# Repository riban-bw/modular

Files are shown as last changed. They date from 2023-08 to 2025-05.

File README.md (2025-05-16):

# riban modular

## Overview

Riban modular is an open source and (where practical) open hardware virtual modular synthesiser with physical control panels that fit the Eurorack physical format. See the [wiki](https://github.com/riban-bw/modular/wiki) for documentation.

There are hardware panels that represent each virtual module. The panels are plugged together via a daisy-chain ribbon cable which provides power and a CAN bus for inter-communication. Modules have rotary controls, switches, LEDs, etc. that mimic and control the virtual modules. A Raspberry Pi 5 forms the core, providing the audio processing and interfacing with the hardware panels. Panels are detected automatically when connected, creating a corresponding virtual module within the virtual modular system.

The system consists of a _Brain_ and panels. The Brain consists of a Raspberry Pi 5, STM32F103 microcontroller, CAN connector, audio interface and associated connectors, buttons, pots, etc. Panels consist of STM32F103 microcontroller, CAN connector and buttons, pots, etc.

Each panel is based on a STM32F103C8 microcontroller with a common firmware that supports various quantities and types of controls and indicators. Each panel has a type number that identifies what type of virtual module it represents.

Connect each module to a ribbon cable connector then power up the system. The core will communicate via CAN to detect which panels are installed, assign each panel an id then add a correspoding virtual module to its model.

## Usage

Hardware panels are required to interface with the firmware. See the [wiki](https://github.com/riban-bw/modular/wiki) for documentation.

## Building

There are two core elements to _riban modular_: Hardware panels (including the firmware that runs on them) and the core. Panel firmware is written in C++ for the STMicroelectronics STM32 range of ARM based microcontrollers. The core is written in C++ for the Raspberry Pi ARM based SBC. VSCode IDE is used by the developer with plugins including platformio, which provides the build platform for the STM32 firmware. VSCode is run on a development PC, connected via ssh to the target (Raspberry Pi) platform.

### Core

The core code runs on a Raspberry Pi (4 or later), running [DietPi](https://dietpi.com/) operating system. CMake is used as the build tool. We use some modules from Bogaudio so have a dependancy on their source code with a small patch to exclude the GUI code. To compile the code:

- Install dependencies, e.g. `sudo apt install build-essentials libjack-jackd2-dev git cmake nlohmann-json3-dev`
- Clone this repository, e.g. `git clone --recursive https://github.com/riban-bw/modular.git`
- Change to the directory, e.g. `cd modular/firmware/rmcore`
- Create a build directory, e.g. `mkdir build`
- Change to the build directory, e.g. `cd build`
- Create build files, e.g. `cmake ..`
- Build executable, e.g. `make`

An executable file called _rmcore_ is creaed in the build directory. This may be run with optional command line options, e.g. `rmcore -h` to show help / usage.

### Panels

Each panel has a platformio configuration. These build instructions are for platformio within vscode IDE. (You could just use platformio directly.) I have written up a [guide](https://github.com/riban-bw/blog/wiki/STM32--development-on-PlatformIO-in-VSCode-on-64-bi-ARM) to using platformio within vscode over ssh to a Raspberry Pi to develop STM32 code. Follow that guide to get a working build environment. There are sepearate platformio projects for each panel, defined by a _platformio.ini_ file in the panel's firmware directory.

- Within vscode, click on the platformio icon in the left toolbar.
- Click on "Open Folder" and open the panel directory.
- If this is the first time, platformio will download and install the STM32 toolkit which may take several minutes.
- Click on the tick icon in the bottom toolbar to build the project. First time build may take longer as it builds all the dependant libraries.

To switch panels, use vscode file menu, open folder... Each time a new panel project is opened for the first time, platformio takes some time to configure. (Even on subsequent switches, platformio can take some time to open a project.)

Be aware that rmcore is within the firmware directory but is not a panel firmware and should be built as described in the [above section](#core).

## CAN Protocol

Communication between the Brain and panels uses CAN two wire serial bus. CAN uses differential balanced cabling to provide robust, high speed communication over long distance. Detection of panels uses CAN extended frame format (to allow fewer frames during detection) whilst normal operation uses standad frame format (to allow shorter frames for realtime data). Each panel starts by advertising its 96-bit hardware UID (STM32 serial number). The Brain module detects new panels and negotiates a _panel id_ (1..63) for each. CAN uses a lowest-id-wins mechanism for bus arbitration which allows the Brain to negotiate each panel partaking in the detection process. The panel with the lowest UUID is assigned the next available panel id which then leaves the detection process and joins the pool of configured panels. The Brain iterates over all panels currently advertising their participation in the detection process.

Subsequent communication between the Brain and each panel is via CAN messages initiated by panels for sensor changes (switches, knobs, etc.) or the Brain for indications (LEDs, etc.). The message type is encoded in the CAN ID. Each panel uses CAN filters to only listen for messages from the Brain. Similarly the Brain listens for messages from panels. All CAN traffic occurs between STM32F103 based devices.

#### CAN Message Protocol

CAN message id is 11-bit (std) or 29-bit (ext) word.

Standard CAN format (11-bit id) is used for runtime realtime messages.

Extended CAN format (29-bit id) is used for configuration and firmware update.

#### CAN runtime realtime messages

Brain to panel (B→P) CAN ID: bit [0] = 0, bits [1:7] = panel id (1..63), bits [8:11] = opcode.

Panel to Brain (B←P) CAN ID: bits [0:7] = 0, bits [8:11] = opcode.

Brain to rmcore splits messages into whole bytes, i.e. CAN ID[1], opcode[1], data[8].

rmcore can send messages to the Brain by setting first byte to 0xFF or to a panel by setting first byte to panel (CAN) id.

CAN payload may have varying length (0..8 bytes) depending on message type.

Brain always listens for panel messages and may request values with appropriate commands. This is asynchronous.

Host (RPi) communicates with Brain via serial port, mostly using same CAN protocol, i.e. the Brain passes through the CAN messages. An exception is for panel detection which the Brain handles locally and passes a single message to the host after detecting each panel.

|B↔P| ID | OpCode | Payload | Purpose|
|---|---|---|---|---|
|B→P| LED | 0x01 | Index [0:7] Mode [0:7] RGB1 [0:23] RGB2 [0:23] | Set LED type and mode. RGB colours are both optional |
|B←P| ADC | 0x02 | PanelId [0:7] Index [0:7] Value [0:15] | ADC value|
|B←P| SW | 0x03 | PanelId [0:7] Index[0:7] EventType [0:7] | See below for event types |
|B←P| ENC | 0x04 | PanelId [0:7] Index [0:7] Value [0:7] | Encoder value +/- |
|B←P| PNL_DUMP | 0xF1 | PanelId [0:7] | Request panel to send its parameter values |
|B←P| ALIVE | 0x0E | | Sent periodically if no other data sent to support watchdog |
|B→P| RESET | 0x0F | | Request panel to reset to detection mode |
|B←H| NUM_PNL  | 0x01 | | Request quantity of detected panels
|B←H| PNL_INFO | 0x01 | | Request type of all panels
|B→H| PNL_INFO | 0x01 | PanelId [0:5] Type [0:31] UUID [0:95] Ver [0:31] | Panel type (sent when new panel detected or PNL_INFO requested)
|B→H| PNL_REMOVED | 0x02 | PanelId [0:5] UUID [0:95] |
|B←H| PNL_RUN  | 0x03 | | Request all panels go to run mode

##### LED Modes
|Value|Mode|
|---|---|
|0x00|Off|
|0x01|Colour 1 on|
|0x02|Colour 2 on|
|0x03|Flash colour 1 / colour 2|
|0x04|Fast flash colour 1 / colour 2|
|0x05|Pulse colour 1 / colour 2|
|0x06|Fast pulse colour 1 / colour 2|

##### Switch States
|Value|State|
|---|---|
|0x00|Release|Sent when a button is released less than 0.5s after it was pressed (short press) or after a long press has triggered|
|0x01|Press|Always sent when a button is pressed|
|0x02|Bold|Sent when a button is released more than 0.5s after it was pressed but a long press has not triggered|
|0x03|Long|Sent when a button is held for longer than 1.5s|

#### Panel Detection

Panels advertise themselves with a CAN message which the Brain detects and starts a negotation. Detection messages use extended CAN ID which is 29-bits long (compared with standard frames used for realtime messages which are 11-bits). Each panel advertises itself by encoding its 96-bit UUID in the CAN ID of 4 consecutive messages. Each message is acknowledged by the Brain, indicating which panel UUID are accepted. Only panels that match that segment of the UUID continue with the negotiation. Eventually only one panel remains and is assigned a panel ID. Finally the panel indicates it has accepted the panel, sending its type and version. This allows the Brain to build a table of panel UUID, panel ID and panel type so that the core can create the appropriate virtual modules. It also allows the Brain to know whether a panel is running old firmware, allowing firmware update. The table is used to ensure that existing panels that restart, e.g. after a firmware update get the same panel ID.

|B⬌P| ID | ID | Payload | Purpose |
|----|---|---|---|---|
|B←P| DETECT_1  | 0x1F<UUID[0:23]>  | | Notify Brain that panel is added to bus but not initialised |
|B→P| DETECT_1  | 0x1F000000 | UUID[0:23] | Brain acknowledges lowest UUID panels |
|B←P| DETECT_2  | 0x1E<UUID[24:47]> | | Panel requests detect stage 2 |
|B→P| DETECT_2  | 0x1E000000 | UUID[24:47] | Brain acknowledges lowest UUID panels |
|B←P| DETECT_3  | 0x1D<UUID[48:71]> | | Panel requests detect stage 3 |
|B→P| DETECT_3  | 0x1D000000 | UUID[48:71] | Brain acknowledges lowest UUID panels |
|B←P| DETECT_4  | 0x1C<UUID[71:95]> | | Panel requests detect stage 4 |
|B→P| DETECT_4  | 0x1C000000 | UUID[72:95] PanelID[0:7] | Brain acknowledges UUID of only remaining panel |
|B←P| ACK_ID | 0x1B0000<PanelId> | Type [0:31] Version [0:31] | Panel acknowledges ID and informs Brain of its version & type |

#### Broadcast messages and firmware update

The CAN ID 0x000 is used to broadcast messages to all panels. This is the highest priority CAN ID (lowest value wins all bus conflict negotiation) and is used for low latency messaging (e.g. synchronisation) and firmware update. The first byte of a broadcast payload data is the opcode for a command. All broadcast messages use standard (11-bit) CAN format.

Broadcast messages
|Dir | ID | ID | Payload | Purpose
|----|---|---|---|---
|B→P| BROADCAST | 0x00000000 | OPCODE[0:7] | Broadcast from Brain payload contains opcode (see below) |
|B→P| BROADCAST | 0x00000000 | 0x01 UUID[0:23] | Start detection - all panels should join detection without software reset |
|B→P| BROADCAST | 0x00000000 | 0x02 PanelType [0:23] Ver [0:31]  | Start firmware update |
|B→P| BROADCAST | 0x00000000 | 0x03 Checksum [0:31] | End firmware update |
|B→P| FIRMWARE  | 0x01000000 | Firmware Block [0:63] | Firmware update data block |
|B→P| BROADCAST | 0x00000000 | 0xFF | Full reset - all panels should perform software reset |

Firmware is started with the broadcast message (CAN ID=0x000) with opcode 0x02. The panel type and firmware version are sent in this message. Any panel of this type with an older firmware will join the firmware update. Subsequent firmware update messages use the CAN ID 0x400 (msb set) with 8 bytes of firmware data. Panels configure a CAN filter to listen to this address during firmware update only. Upon completion of firmware update the Brain sends broadcast message with opcode 0x03 and a 32-bit checksum of the firmware data. The Brain ends its firmware update. Panels validate the checksum then apply the new firmware, restart and advertise as new panels.

#### Watchdog

Each panel periodically sends an ALIVE message if no other message has been sent in the previous 1.5s. If the Brain has not received any message from a panel for longer than 2s it assumes the panel has been removed  from the bus and removes its entry from the panel table. This triggers removal of the corresponding virtual module.

## Configuration

Configuration is stored in config.json which is loaded before command line parameters are parsed, so command line parameters take precedent.

Global settings are defined in the "global" object.

```
{
    "global": { # Global settings
        "polyphony": 1 # Quantity of concurrent voices (1..16)
    }
}
```

Each panel is defined in "panel" object.

```
{
    "panels" : { # Object of panel types
        "1": { # Object of panel configuration indexed by panel type id
            "module": "vco", # Name of the module type this panel controls
            "buttons": [ # List of buttons, indexed by physical button number
                [0, # Button function (input, poly input, output, poly output, param)
                0], # Index of the parameter or input/output
                # .. more button configs
            ],
            "leds": [ # List of LEDs, indexed by physical LED number
                [0, # LED function  (input, poly input, output, poly output, param)
                0], # Index of parameter or input/output
                # ... more LEDs
            ],
            "adcs": [ # List of parameters, indexed by physical ADC number
                0, # Parameter index
                # ... more ADCs
            ]
            "encs": { # List of parameters, indexed by physical PEC11 encoder number
                0, # Parameter index
                # ... more encoders
            }
        }, # ... More panel types
    }
}
```

panel_types.h defines mapping of panel types to module types and defines the STM32F103 pins used for sensors (controls) on each panel. 

## License

_riban modular_ is free and open source software, avaialble for distibution, use and modification by all. It has three open source licences, each applied to different parts of the code. Each source code file (including headers) contain a copyright notice describing which license applies to that part of the code. If a file is missing this banner, LGPL v3 is applied.

### LGPL V3
LGPL v3 is used for the core software and some plugins. This protects the core application whilst allowing non-open source plugins to be hosted by exercising dynamic linking with runtime loading (plugin exception). The text of the LGPL v3 license is distributed with the source code within the file called, lgpl-3.0.txt and may also be obtained from https://www.gnu.org/licenses/lgpl-3.0.en.html.

### GPL V3
To support plugins derived from GPL licensed code, some plugins have been licenced using GPL v3. These plugins continue to be fully copy-left protected whilst also able to be loaded into the core application using dynamic linking with runtime loading (plugin exception). The text of the GPL v3 license is distributed with the source code within the file called, gpl-3.0.txt and may also be obtained from https://www.gnu.org/licenses/gpl-3.0.en.html.

### MIT
To encourage third party plugin developement, there is a plugin template released under MIT license. This permits the use of the template as the basis of new plugins with the option for the author to release the derived work under any other license. We encourage use of LGPL for plugins where an open source license is required or preferred.

### Guidance and advice for plugin creators

If you are creating plugins to run within _riban modular_, you may use the `template.h` and `template.cpp` files as the boiler plate code. These files are published under the MIT license, specifically to allow and encourage developers to create new plugins without restricitve licensing constraints. You may create a new plugin and use the _riban modular_ cmake based build system to create the shared library. You may release this under a license that best suits your use case. You must attribute riban ltd as the author of the original template code, as described in the template source code.

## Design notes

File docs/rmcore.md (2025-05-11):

# Anatomy of rmcore source code

## Introduction
_riban modular_ has a module called the _Brain_. This does all the DSP, much of the physical interfacing and handles the logic for modules and panel management. It consists of a SBC (Raspberry Pi) running DietPi (Debian based) OS, a STM32 based microcontroller and I2S based soundcard. The STM32 performs CAN bus management and communicates with the SBC via a serial port. The program running on the SBC is called rmcore. This manages the state model and is the subject of this document.

## Purpose
This document describes the structure and data flows of rmcore. It acts as an engineering guide for software and hardware developers.

## Source Code
The source code for rmcore consists of the following source files, stored in `firmware/rmcore/src` directory:

- rmcore.cpp Implementation of core functionality and logic.
- moduleManager.cpp Implementation of the ModuleManager class that manages individual modules.
- usart.cpp Implementation of serial port interface, including CAN messaging.
- util.cpp Implementation of command line output helper functions.

Corresponding header files that declare classes are stored in `firmware/rmcore/include` directory.

## Initialisation
_rmcore_ is a command line application writeen in C++. It has a `int main(int argc, char** argv)` initialisation function. The return code is non-zero on an error. Command line parameters are parsed based on standard short (-c) and long (--command) syntax.

At initialisation, a handler is defined for signals. This allows capture of signals like SIGINT, allowing clean exit from the main program loop.

The command line is parsed for options.

A configuration file in json format is loaded and parsed by `loadConfig()` function.

`g_poly` is checked to allow it to be set by config or command line.

The command line interface (CLI) is initialised, including loading previous sessions' history.

A jack client is created which is used to control routing and monitor for changes and errors, e.g. xruns.

Polyphony is set, based on configuration and command line parameters.

A state model is loaded from a snapshot file. This may be defined by a command line parameter or the previous state is restored.

A reset message is sent to the _Brain_ microcontroller which should trigger panels to enter detection mode.

## Main program loop

Current time is updated and per-second events triggered.

- Recently detected panels are set to run mode.
- Panels are checked and removed if no messages received in past 5s.
- If state has changed within previous minute, it is stored to a snapshot.

CLI messages are processed.

Hardware panels are processed, checking for change of parameters, buttons, etc. and reacting to panels being added.

LED state off each module is checked and hardware panels updated if change of state.

## Configuration

The `loadConfig()` and `saveConfig()` functions use a json formated configuration file. This configuration is held in the same format at runtime and accessed via nlohmann::json library. The configuration is loaded at start-up and saved at exit.

## Command line parsing

_rmcore_ uses standard *nix style command line arguments in the short (-c) and long (--command) format. The `bool parseCmdline(int argc, char** argv)` function takes the command line arguments and configures global variables using the getopt library. This is a fairly standard and simple, itarative loop that looks for each argument and parses via a `switch` statement.

## Helper print functions

There are three helper functions that act like `fprintf`, adding an appropriate prefix and directing to the apporopriate outpute (stdout or stderr). Output only occurs at the corresponding verbose level defined by command line argument -v, --verbose.

`void debug(const char *format, ...)` prints to stderr at debug verbose level with no prefix.
`void info(const char *format, ...)` prints to stdout at info and debug verbose levels with no prefix.
`void error(const char *format, ...)` prints to stderr at all* verbose levels with "ERROR: " prefix.

* There is no output at silent verbose level.

## Command line interface (CLI)

The `readline` library is used to provide a CLI with history. The CLI history is saved on exit and restored on startup. During each main program loop, stdin is checked for a character which is added to the CLI input buffer. When a newline is detected, `void handleCli(char* line)` is called which parses the line and triggers actions. Most actions are single character commands, prefixed with '.', followed immediately by the first parameter with subsequent parameters seperated by commas with no white space (other than required within a parameter), e.g. ".svco,0,1.2" to set the first parameter of the "vco" module to a value of 1.2.

The stdin check has a 10us timeout which, when no key has been pressed, provides sufficient delay in main loop to avoid high CPU usage.

## Jack client

During initalisation, a jack client is created and callbacks configured port connect / disconnect and xrun. Port connection is only used for debug. Xrun count is maintained and available for debug and/or display.

The jack client is used to manipulate the jack graph. `bool connect(std::string source, std::string destination)` connects two nodes. `bool disconnect(std::string source, std::string destination)` disconnects two nodes. If a port is defined as polyphonic then all polyphonic connections are controlled. Polyphonic ports are suffixed with "[x]" where 'x' is the polyphony channel.

The jack client is used to get the jack graph state during saving of snapshots and is deactivated during exit.

## Module manager

During initialisation, an instance of a singleton class `ModuleManager` is created. This manages module plugins and is described in more detail in other documentation.

## State snapshot management

The runtime model state is stored to and recalled from _snapshot_ files with filename extenstion ".rms" (riban modular snapshot (or state)). This is in the _json_ format. Snapshots are stored in the "snapshot" subdirectory of the "config" directory. `void loadState(const std::string& filename)` opens the file and iterates each line, looking for "[section]" and "param=value" entries, populating the runtime state. Similarly, `void saveState(const std::string& filename)` iterates the runtime state, storing these entries in the file.

## Core / Brain interface

There is a serial port connection between the SBC and _Brain_ STM32 module which is used for communication between _rmcore_ and the module hardware. The `USART` class handles this communication and is documented elsewhere. _rmcore_ uses an instance of `USART` to send commands to the _Brain_ with _void txCmd(uint8_t cmd)` and directly to panels via the _Brain's_ CAN bus pass-through, `void txCAN(uint8_t pnlId, uint8_t opcode, uint8_t* data, uint8_t len)`.

Within the main progam loop, `bool processPanels()` is called approximately every millisecond. This reads messages from the USART into a buffer then parses complete messages. (See USART documentation for details of on-the-wire data encoding using COBS.) Changes of state in the hardware are detected. Model state and module plugins are updated.

`void processLeds()` is also called approximately every millisecond. This checks if any modules have changed the state of their LEDs and sends corresponding CAN messages through the _brain_ to panels which update their physical displays. There are LED states which define the behaviour or each LED. The hardware panels perform the animation, like pulsing which reduces traffic on the CAN bus and processing in _rmcore_.

## Realtime processing

All realtime processing is done within each module's _process()_ function which is called by its jack client. See module documentation for detail. There is no realtime processing performed within _rmcore_ source code, although it does host each of the plugins. Panel control and monitoring is performed within the main program loop which has a 10us delay in each loop to reduce CPU load (see CLI).

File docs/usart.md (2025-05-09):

# Anatomy of usart source code

## Introduction
_riban modular_ interfaces its SBC with its STM32 microcontroller based _Brain_ module via a serial port. USART is a class that provides this interface and is the subject of this document.

## Purpose
This document describes the structure and data flows of USART. It acts as an engineering guide for software and hardware developers.

## Source Code
The USART class is declared within "usart.h" within the `firmware/rmcore/include` directory and is implemented within "usart.cpp" within the `firmware/rmcore/src` directory. See rmcore documentation for details of other source code that may also be used.

## Initialisation

The `USART(const char* dev, speed_t baud)` constructor configures the device as a non-blocking, 8-bit serial port. It sets the `rxData` pointer to the start of the data payload of the receive buffer. 

## Methods

All public methods have inline documentation that can produce API documentation via doxygen.

## Sending data

The `void tx(uint8_t* data, uint8_t len)` function encodes a data buffer using COBS encoding and sends it to the serial port. There are two wrappers for this function; `void txCAN(uint8_t pnlId, uint8_t opcode, uint8_t* data, uint8_t len)` to send data to the CAN bus (which the _Brain_ transfers) and `void txCmd(uint8_t cmd)` for sending commands directly to the _Brain_.

There are three versions of `setLed` function which allow partial of full configuration of panel LEDs. The partial configuration reduces CAN bus traffic.

## Receiving data

The `int rx()` function checks for data, decodes from COBS and leaves it in the receive buffer. This should be called regularly and data parsed before next call. This is done by _rmcore_.

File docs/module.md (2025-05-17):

# Anatomy of module source code

## Introduction
_riban modular_ has a plugin system for its DSP modules. Each module is provided by a shared library with a common API, inheriting from the _Module_ base class. This is the subject of this document.

## Purpose
This document describes the structure and data flows of Module class. It acts as an engineering guide for software and hardware developers.

## Source Code
The Module class is declared and implemented within "module.hpp" within the `firmware/rmcore/include` directory. See rmcore documentation for details of other source code that may also be used. Each plugin module is implemented in its own source and header files in the `firmware/plugins` directory.

## Initialisation

There is a macro `DEFINE_PLUGIN(CLASSNAME)` that provides the `extern "C" Module* createPlugin()` function for each child class. This allows a class to inherit Module and be instantiated by the module manager with minimal boilerplate code.

A default constructor is defined which does nothing. Child classes should reimplement a default constructor that populates `m_moduleInfo` with inputs, outputs, parameters, LEDs, etc. Non-polyphonic inputs and output are defined before polyponic ones so ensure `enum` are in the correct order.

The `bool _init(const std::string& uuid, void* handle, uint8_t poly, uint8_t verbose)` function is called after instantiation because modules must use static functions to access jack library which may not be defined until the object is created, i.e. after constructor returns. Child classes should call `_init` from their `init` function.

Within the `_init` function, the module deduces its name by demangling the class name from the shared library and stores it in its `ModuleInfo` structure. Library handle used to close library and verbose level used for console messages are stored.

A jack client is created with the module's uuid as its name. This is derived from the hardware panel's uuid or _rmcore's_ virtual module management. The `m_moduleInfo` stucture is used to create jack input and output ports. Polyphonic ports are duplicated for each channel of polyphony with suffix [x] where 'x' is the polyphonic channel.

Vector entires are created for parameters and LEDs with default values. Child classes should populate with valid defaults within the `init` function.

## Methods

All public methods have inline documentation that can produce API documentation via doxygen.

## DSP processing

The `int process(jack_nframes_t frames)` function is overriden in child classes to implement digital signal processing. This is run within jack's realtime thread and should not block or unduely delay. It should always return 0, otherwise the application will terminate. Slow running `process` functions may trigger xruns causing disruption to audio output. There is a `jack_default_audio_sample_t*` data buffer of size `frames` available for each input and output which may be accessed with `(jack_default_audio_sample_t*)jack_port_get_buffer(m_output[PORT_INDEX], frames)` function. `m_output` should be replaced with `m_polyOutput` to get polyphonic output buffer, `m_input` to get input buffer and `m_polyInput` to get polyphonic input buffer.

## Parameters

Parameters are all `floats` stored in a vector. The `bool setParam(uint32_t param, float val)` and `const std::string& getParamName(uint32_t param)` by default store and recall these values but may be overriden to process values in child classes. Pot/knob parameters are normalised to the range 0.0 to 1.0.

## Polyphony

The `void setPolyphony(uint8_t poly)` function is called by module manager. It removes and creates jack ports to match the polyphony.

## Inheritance

_Module_ is the base class for module plugins. There is a _template.h_ and _template.cpp_ file that show the minimum code to create a plugin, inheriting from _Module_. The template has comments describing each section.

- The constructor should be overriden to populate the moduleInfo structure that is subsequently used to create inputs, outputs, parameters, etc. Other initialisation should not be done here (see `init()`) because some elements (particularly jack ports) are not created in the constructor.
- `void init()` should be overriden to perform initialisation of the module. This is called after the module object is created and jack ports, parameter variables, etc. are created.
- `int process(jack_nframes_t frames)` should be overriden to implement the DSP of the module. Audio and CV processing is done here within the realtime thread of jack.

The CMake build system will build all plugins that have source code within the `firmware/rmcore/plugins/src` directory. There should not be a need to adjust the CMake build system.

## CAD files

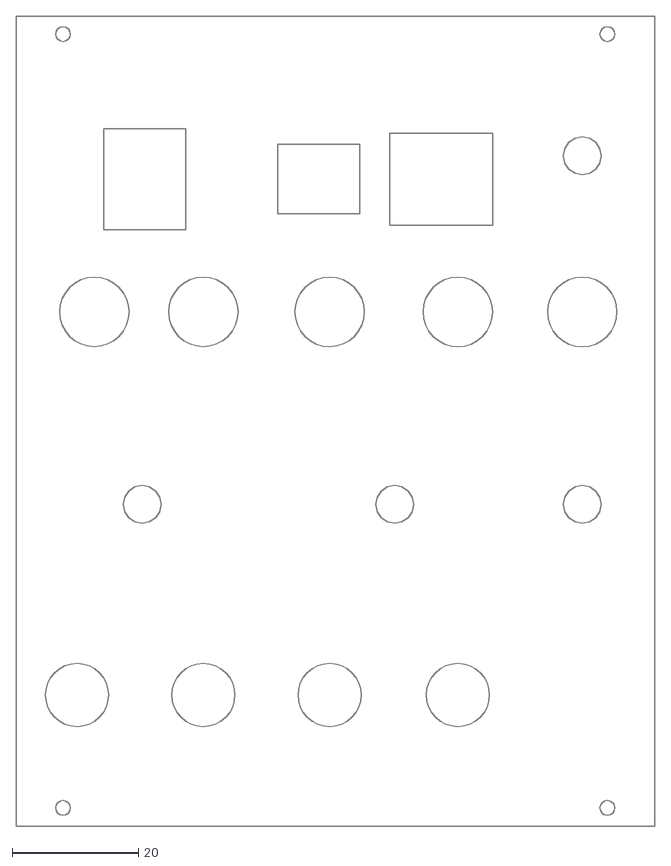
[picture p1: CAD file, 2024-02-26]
panels/fronts/brain.dxf
101.1 x 128.3

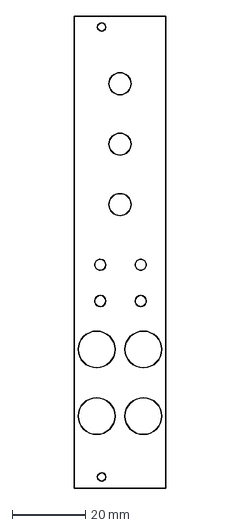
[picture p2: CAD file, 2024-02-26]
panels/fronts/bogaudio_lvcf.dxf
25.0 x 128.5 mm

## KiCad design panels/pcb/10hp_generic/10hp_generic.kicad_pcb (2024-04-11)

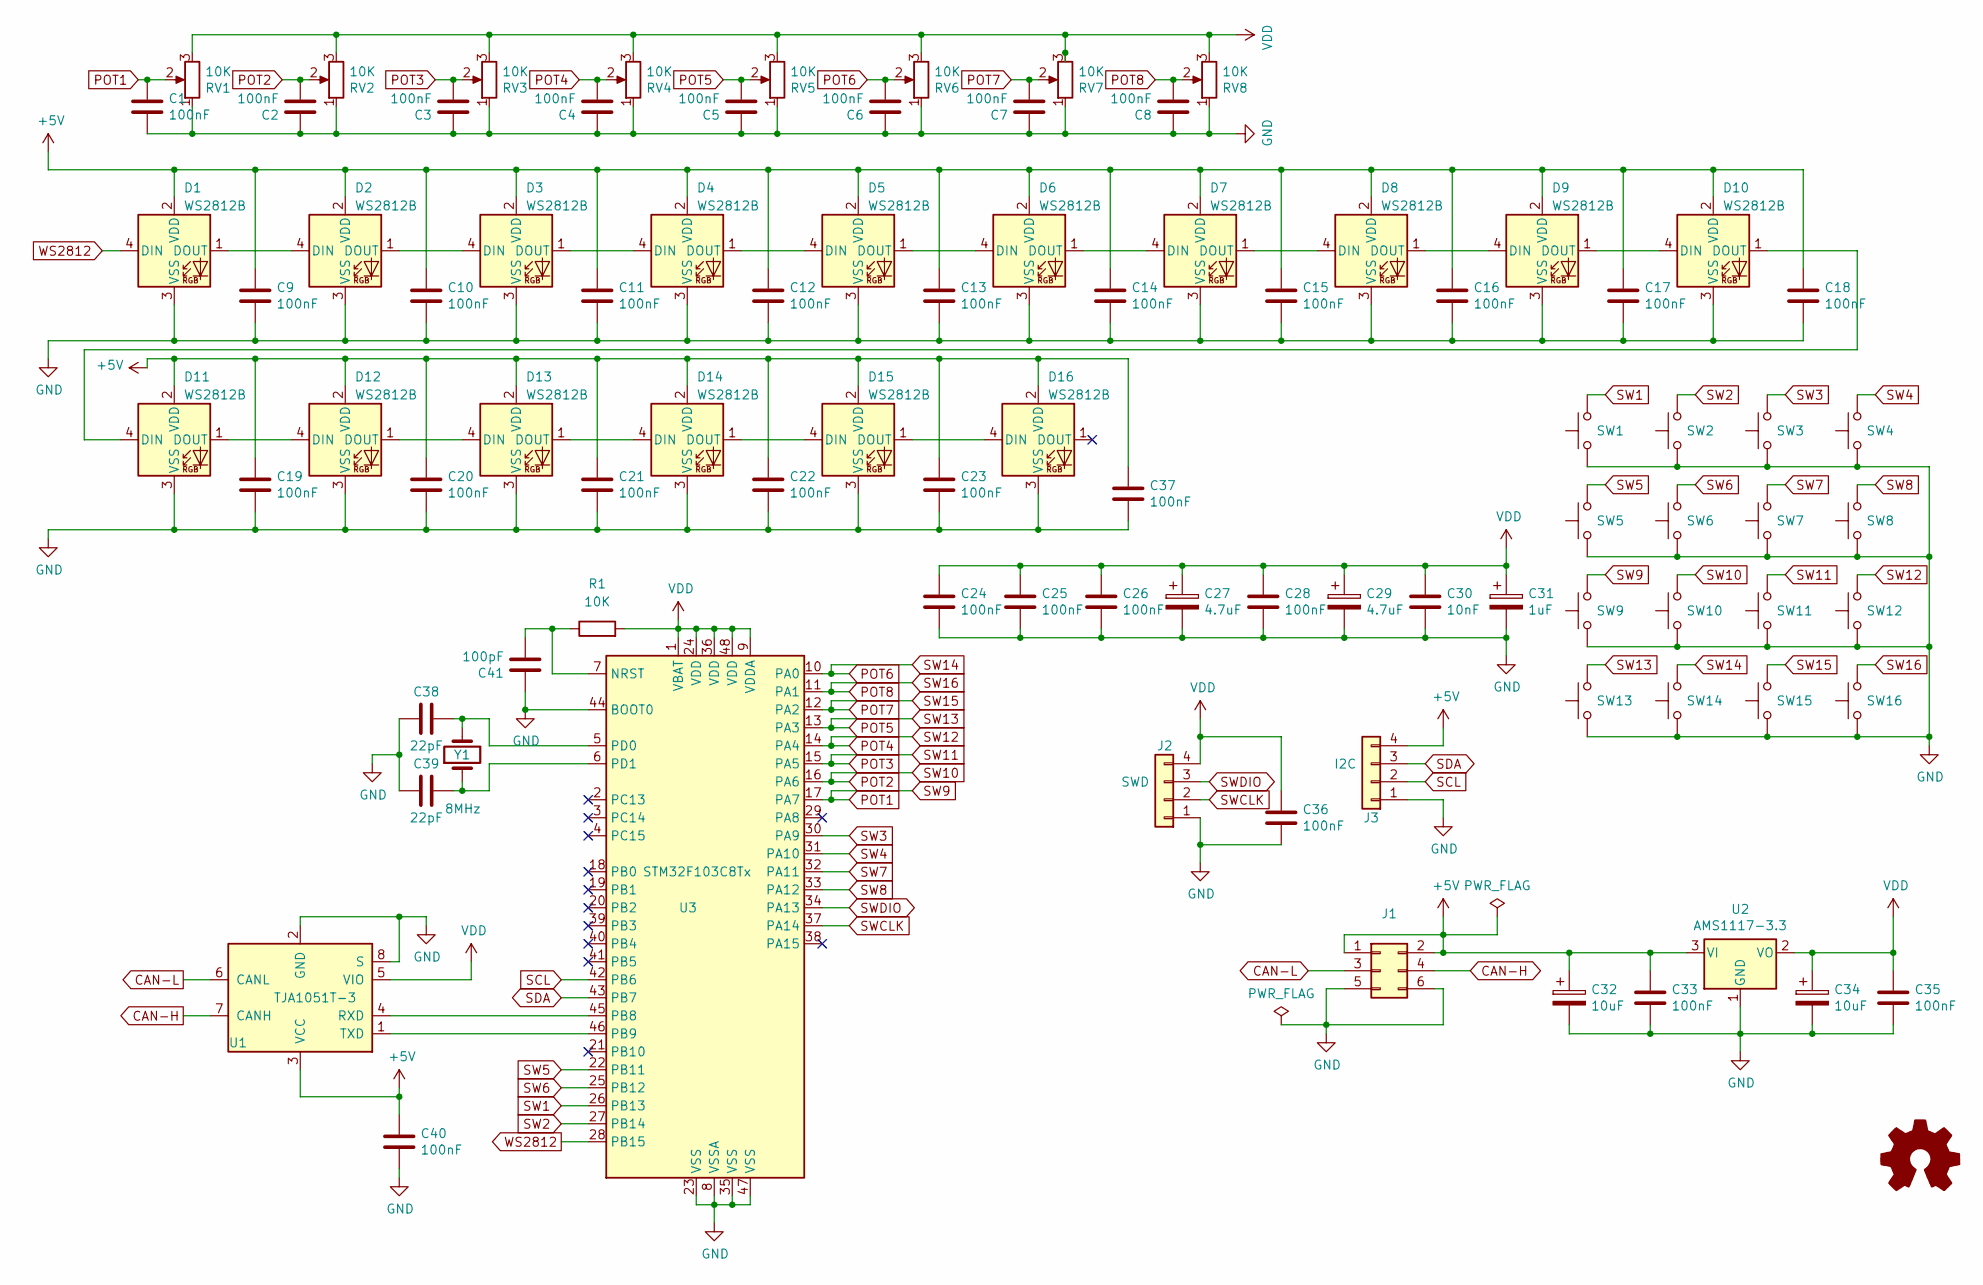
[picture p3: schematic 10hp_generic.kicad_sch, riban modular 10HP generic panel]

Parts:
C1, C2, C3, C4, C5, C6, C7, C8, C9, C10, C11, C12, C13, C14, C15, C16, C17, C18, C19, C20, C21, C22, C24, C25, C26, C28, C33, C35, C36, C40: 100nF; C_0402_1005Metric; LCSC C1525
C23, C37: 100nF; C_0603_1608Metric; LCSC C14663
C27, C29: 4.7uF; C_0805_2012Metric; LCSC C1779
C30: 10nF; C_0402_1005Metric; LCSC C15195
C31: 1uF; C_0402_1005Metric; LCSC C52923
C32, C34: 10uF; C_0805_2012Metric; LCSC C15850
C38, C39: 22pF; C_0603_1608Metric; LCSC C326840
C41: 100pF; C_0402_1005Metric; LCSC C1546
D1, D2, D3, D4, D5, D6, D7, D8, D9, D10, D11, D12, D13, D14, D15, D16: WS2812B; LED_XL-1615RGBC-WS2812B; LCSC C5349954
J1: CAN_PWR; IDC-Header_2x03_P2.54mm_Vertical
J2: SWD; PinHeader_1x04_P2.54mm_Vertical
J3: I2C; PinHeader_1x04_P2.54mm_Vertical
R1: 10K; R_0402_1005Metric
RV1, RV2, RV3, RV4, RV5, RV6, RV7, RV8: 10K; Potentiometer_9mm_Vertical; LCSC C470336
SW1, SW2, SW3, SW4, SW5, SW6, SW7, SW8, SW9, SW10, SW11, SW12, SW13, SW14, SW15, SW16: SW_Push; SW_PUSH_6mm_H4.3mm; LCSC C5260475
U1: TJA1051T-3; SOIC-8_3.9x4.9mm_P1.27mm; LCSC C38695
U2: AMS1117-3.3; SOT-223; LCSC C6186
U3: STM32F103C8Tx; LQFP-48_7x7mm_P0.5mm; LCSC C8734
Y1: 8MHz; HC-49S; LCSC C12674

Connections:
+5V: C9.1, C10.1, C11.1, C12.1, C13.1, C14.1, C15.1, C16.1, C17.1, C18.1, C19.1, C20.1, C21.1, C22.1, C23.1, C32.1, C33.1, C37.1, C40.1, D1.2 (VDD), D2.2 (VDD), D3.2 (VDD), D4.2 (VDD), D5.2 (VDD), D6.2 (VDD), D7.2 (VDD), D8.2 (VDD), D9.2 (VDD), D10.2 (VDD), D11.2 (VDD), D12.2 (VDD), D13.2 (VDD), D14.2 (VDD), D15.2 (VDD), D16.2 (VDD), J1.1, J1.2, J3.4, U1.3 (VCC), U2.3 (VI)
CAN-H: J1.4, U1.7 (CANH)
CAN-L: J1.3, U1.6 (CANL)
GND: C1.2, C2.1, C3.1, C4.1, C5.1, C6.1, C7.1, C8.1, C9.2, C10.2, C11.2, C12.2, C13.2, C14.2, C15.2, C16.2, C17.2, C18.2, C19.2, C20.2, C21.2, C22.2, C23.2, C24.2, C25.2, C26.2, C27.2, C28.2, C29.2, C30.2, C31.2, C32.2, C33.2, C34.2, C35.2, C36.2, C37.2, C38.1, C39.1, C40.2, C41.1, D1.3 (VSS), D2.3 (VSS), D3.3 (VSS), D4.3 (VSS), D5.3 (VSS), D6.3 (VSS), D7.3 (VSS), D8.3 (VSS), D9.3 (VSS), D10.3 (VSS), D11.3 (VSS), D12.3 (VSS), D13.3 (VSS), D14.3 (VSS), D15.3 (VSS), D16.3 (VSS), J1.5, J1.6, J2.1, J3.1, RV1.1, RV2.1, RV3.1, RV4.1, RV5.1, RV6.1, RV7.1, RV8.1, SW1.1, SW2.1, SW3.1, SW4.1, SW5.1, SW6.1, SW7.1, SW8.1, SW9.1, SW10.1, SW11.1, SW12.1, SW13.1, SW14.1, SW15.1, SW16.1, U1.2 (GND), U1.8 (S), U2.1 (GND), U3.8 (VSSA), U3.23 (VSS), U3.35 (VSS), U3.44 (BOOT0), U3.47 (VSS)
unnamed: D1.1 (DOUT), D2.4 (DIN)
unnamed: D2.1 (DOUT), D3.4 (DIN)
unnamed: D3.1 (DOUT), D4.4 (DIN)
unnamed: D4.1 (DOUT), D5.4 (DIN)
unnamed: D5.1 (DOUT), D6.4 (DIN)
unnamed: D6.1 (DOUT), D7.4 (DIN)
unnamed: D7.1 (DOUT), D8.4 (DIN)
unnamed: D8.1 (DOUT), D9.4 (DIN)
unnamed: D9.1 (DOUT), D10.4 (DIN)
unnamed: D10.1 (DOUT), D11.4 (DIN)
unnamed: D11.1 (DOUT), D12.4 (DIN)
unnamed: D12.1 (DOUT), D13.4 (DIN)
unnamed: D13.1 (DOUT), D14.4 (DIN)
unnamed: D14.1 (DOUT), D15.4 (DIN)
unnamed: D15.1 (DOUT), D16.4 (DIN)
unnamed: U1.4 (RXD), U3.45 (PB8)
unnamed: U1.1 (TXD), U3.46 (PB9)
unnamed: C41.2, R1.1, U3.7 (NRST)
unnamed: C38.2, U3.5 (PD0), Y1.2
unnamed: C39.2, U3.6 (PD1), Y1.1
POT1: C1.1, RV1.2, SW9.2, U3.17 (PA7)
POT2: C2.2, RV2.2, SW10.2, U3.16 (PA6)
POT3: C3.2, RV3.2, SW11.2, U3.15 (PA5)
POT4: C4.2, RV4.2, SW12.2, U3.14 (PA4)
POT5: C5.2, RV5.2, SW13.2, U3.13 (PA3)
POT6: C6.2, RV6.2, SW14.2, U3.10 (PA0)
POT7: C7.2, RV7.2, SW15.2, U3.12 (PA2)
POT8: C8.2, RV8.2, SW16.2, U3.11 (PA1)
SCL: J3.2, U3.42 (PB6)
SDA: J3.3, U3.43 (PB7)
SW1: SW1.2, U3.26 (PB13)
SW2: SW2.2, U3.27 (PB14)
SW3: SW3.2, U3.30 (PA9)
SW4: SW4.2, U3.31 (PA10)
SW5: SW5.2, U3.22 (PB11)
SW6: SW6.2, U3.25 (PB12)
SW7: SW7.2, U3.32 (PA11)
SW8: SW8.2, U3.33 (PA12)
SWCLK: J2.2, U3.37 (PA14)
SWDIO: J2.3, U3.34 (PA13)
VDD: C24.1, C25.1, C26.1, C27.1, C28.1, C29.1, C30.1, C31.1, C34.1, C35.1, C36.1, J2.4, R1.2, RV1.3, RV2.3, RV3.3, RV4.3, RV5.3, RV6.3, RV7.3, RV8.3, U1.5 (VIO), U2.2 (VO), U3.1 (VBAT), U3.9 (VDDA), U3.24 (VDD), U3.36 (VDD), U3.48 (VDD)
WS2812: D1.4 (DIN), U3.28 (PB15)

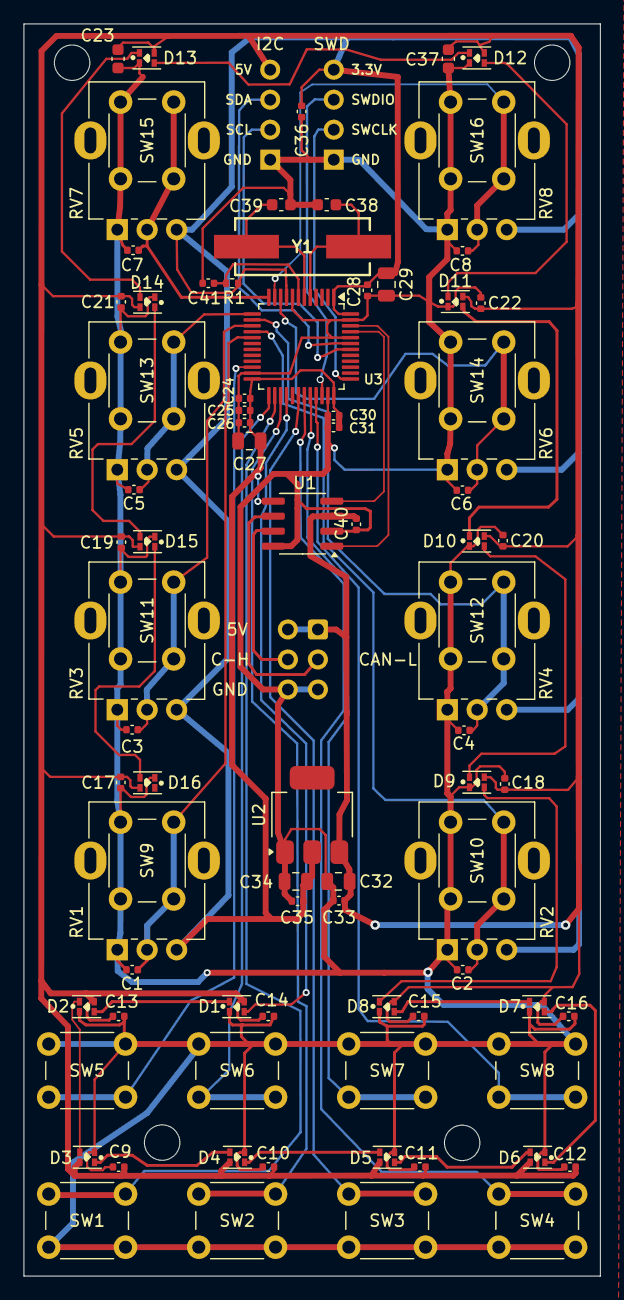
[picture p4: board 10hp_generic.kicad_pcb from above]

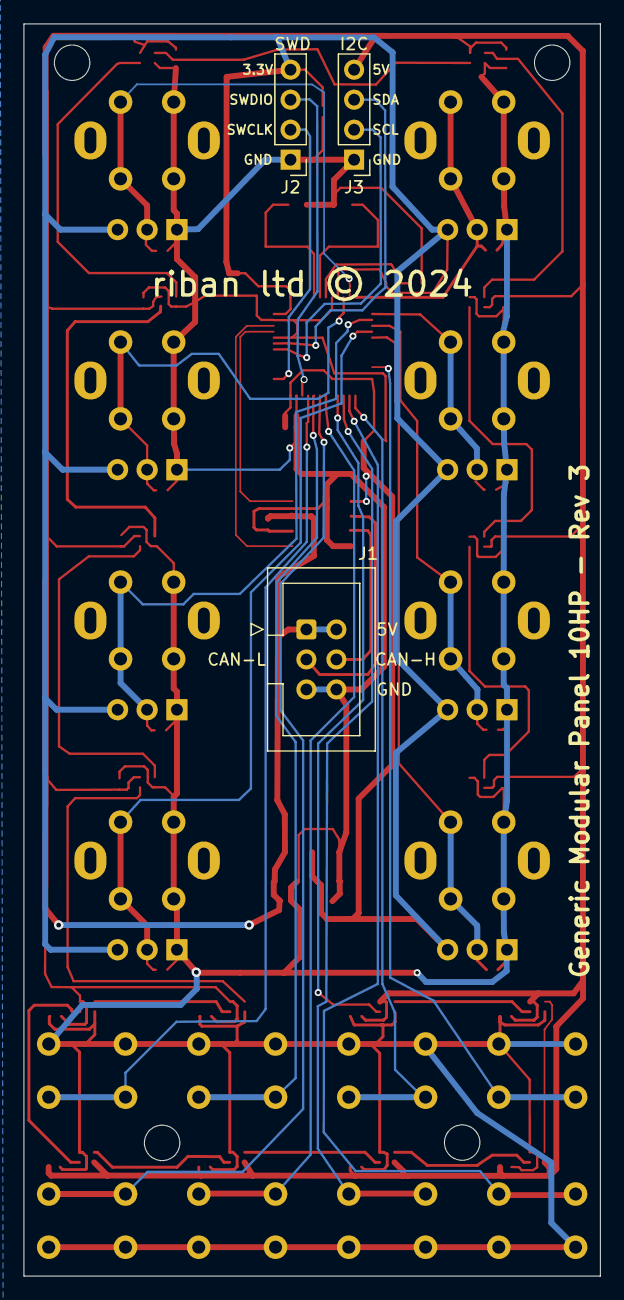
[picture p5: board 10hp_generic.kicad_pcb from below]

Board: 2 copper layers, 48.8 x 106.0 mm, 89 parts (3 on the bottom side), 46 nets.

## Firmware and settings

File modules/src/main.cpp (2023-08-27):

/* riban modular
  
  Copyright 2023 riban ltd <info@riban.co.uk>

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
  Provides the core firmware for hardware modules implemented on STM32F107C microcontrollers.
  Modules are generic using the same firmware and are configured at compile time using preprocessor directive MODULE_TYPE
*/

#include <Arduino.h>
#include <Wire.h> // I2C inteface
#include "modular.h"
#include "ws2812.h"

#define NEXT_MODULE_PIN PC14 // GPI connected to next module's reset pin
#define LEARN_I2C_ADDR 0x77 // I2C address to use when reset

const static uint32_t module_type = MODULE_TYPE;

bool configured = false; // True when initialised and I2C address set
uint32_t i2cValue = 0; // Received I2C value to read / write
uint8_t i2cCommand = 0; // Received I2C command
uint8_t avCount = 0; // Index of ADC averaging filter
uint8_t muxAddr = 0; // Multiplexer address [0..7]
uint16_t switchValues[16]; // 32-bit flags representing value of banks of 32 GPI / switches
uint32_t scheduledFlash = 0; // Time that next LED flash change will occur
uint32_t scheduledFastFlash = 0; // Time that next LED flash change will occur
uint32_t scheduledPulse = 0; // Time that next LED pulse change will occur
uint32_t scheduledFastPulse = 0; // Time that next LED pulse change will occur
uint32_t reset_time = -1;
bool ledMute = false; // True to turn off all LEDs but retain config
bool flashOn = false; // True when flash is on
bool fastFlashOn = false; // True when fast flash is on
bool pulseDir = true; // True when pulse is increasing
uint8_t pulsePhase = 0; // Step through pulse fade
bool fastPulseDir = true; // True when fast pulse is increasing
uint8_t fastPulsePhase = 0; // Step through fast pulse fade
uint64_t changedFlags = 0; // Bitwise flags indicating a sensor value has changed
uint8_t i2cAddr = LEARN_I2C_ADDR; // Module's I2C address

struct SWITCH {
  uint8_t gpi; // GPI pin
  bool value = 0; // Current value
  uint32_t lastChange = 0; // Time of last value change
};

struct ADC {
  uint8_t gpi; // GPI pin
  uint32_t sum = 0; // Sum of last 16 samples
  uint16_t value = 0; // Current filtered / averaged value
  uint16_t lastValue = 0; // Last retrieved filtered / averaged value
  uint16_t avValues[16] = {0,0,0,0,0,0,0,0,0,0,0,0,0,0,0,0}; // Last 16 samples
};

struct LED {
  uint8_t gpi; // GPI pin
};

struct WS_LED {
    uint8_t led; // Index of LED in WS2812 chain
    uint8_t mode = 0; // WS2812_MODE
    uint8_t r1 = 100; // Primary red value
    uint8_t g1 = 100; // Primary green value
    uint8_t b1 = 0; // Primary blue value
    uint8_t r2 = 10; // Secondary red value
    uint8_t g2 = 10; // Secondary green value
    uint8_t b2 = 0; // Secondary blue value
    uint32_t value = 0; // Current value 0x00rrggbb used by fade
    bool dir = true; // Fade direction for pulse or state for flash
};

struct SWITCH switches[SWITCHES];
struct ADC adcs[ADCS];
struct LED leds[LEDS];
struct WS_LED wsleds[WSLEDS];

// Process switches
void processSwitches(uint32_t now) {
  //!@todo Add stretching, long press, etc.
  for (uint16_t i = 0; i < SWITCHES; ++i) {
    if (now - switches[i].lastChange < 20)
      continue; //debounce
    bool state = !digitalRead(switches[i].gpi);
    if (state != switches[i].value) {
      switches[i].value = state;
      switches[i].lastChange = now;
      switchValues[muxAddr] ^= (-state ^ switchValues[muxAddr]) & (1UL << i);
      changedFlags |= 1ULL << muxAddr;
      Serial.printf("Switch %d changed to %d\n", i, state);
    }
  }
}

// Process ADCs
void processAdcs(uint32_t now) {
  for (uint16_t i = 0; i < ADCS; ++i) {
    uint16_t value = analogRead(adcs[i].gpi);
    adcs[i].sum -= adcs[i].avValues[avCount];
    adcs[i].avValues[avCount] = value;
    adcs[i].sum += value;
    value = adcs[i].sum / 16;
    if (value != adcs[i].value) {
      changedFlags |= (1ULL << (0x10 + i));
      adcs[i].value = value;
    }
  }
  if (++avCount > 15)
    avCount = 0;
}

// Process WS2812 animation
void processWs2812(uint32_t now) {
  if (ledMute)
    return;
  bool doFlash = scheduledFlash < now;
  bool doFastFlash = scheduledFastFlash < now;
  bool doPulse = scheduledPulse < now;
  bool doFastPulse = scheduledFastPulse < now;
  if (doFlash) {
    flashOn = !flashOn;
    scheduledFlash += 500;
  }
  if (doFastFlash) {
    fastFlashOn = !fastFlashOn;
    scheduledFastFlash += 100;
  }
  if (doPulse) {
    if (pulseDir) {
      if(++pulsePhase == 255)
        pulseDir = false;
    } else {
      if(--pulsePhase == 0)
        pulseDir = true;
    }
    scheduledPulse += 10;
  }
  if (doFastPulse) {
     if(++fastPulsePhase == 255)
        fastPulseDir = false;
  } else {
    if(--pulsePhase == 0)
      fastPulseDir = true;
    scheduledFastPulse += 5;
  }
  for (uint16_t i = 0; i < WSLEDS; ++i) {
      if(wsleds[i].mode == WS2812_MODE_OFF) {
          ws2812_set(wsleds[i].led, 0, 0, 0);
          wsleds[i].mode = WS2812_MODE_IDLE;
          wsleds[i].dir = false;
      } else if (wsleds[i].mode == WS2812_MODE_ON) {
          ws2812_set(wsleds[i].led, wsleds[i].r1, wsleds[i].g1, wsleds[i].b1);
          wsleds[i].mode = WS2812_MODE_IDLE;
          wsleds[i].dir = true;
      } else if (wsleds[i].mode == WS2812_MODE_ON2) {
          ws2812_set(wsleds[i].led, wsleds[i].r2, wsleds[i].g2, wsleds[i].b2);
          wsleds[i].mode = WS2812_MODE_IDLE;
          wsleds[i].dir = true;
      } else if (wsleds[i].mode == WS2812_MODE_SLOW_FLASH && doFlash) {
          if (flashOn) {
            ws2812_set(wsleds[i].led, wsleds[i].r2, wsleds[i].g2, wsleds[i].b2);
          } else {
            ws2812_set(wsleds[i].led, wsleds[i].r1, wsleds[i].g1, wsleds[i].b1);
          }
      } else if (wsleds[i].mode == WS2812_MODE_FAST_FLASH && doFastFlash) {
          if (fastFlashOn) {
            ws2812_set(wsleds[i].led, wsleds[i].r2, wsleds[i].g2, wsleds[i].b2);
          } else {
            ws2812_set(wsleds[i].led, wsleds[i].r1, wsleds[i].g1, wsleds[i].b1);
          }
      } else if (wsleds[i].mode == WS2812_MODE_SLOW_PULSE && doPulse) {
          uint8_t r = wsleds[i].value >> 16;
          uint8_t g = wsleds[i].value >> 8;
          uint8_t b = wsleds[i].value;
          r = (wsleds[i].r1 - wsleds[i].r2) * pulsePhase / 256 + wsleds[i].r2;
          g = (wsleds[i].g1 - wsleds[i].g2) * pulsePhase / 256 + wsleds[i].g2;
          b = (wsleds[i].b1 - wsleds[i].b2) * pulsePhase / 256 + wsleds[i].b2;
        wsleds[i].value = r << 16 | g << 8 | b;
        ws2812_set(wsleds[i].led, r, g, b);
      } else if (wsleds[i].mode == WS2812_MODE_FAST_PULSE && doFastPulse) {
          uint8_t r = wsleds[i].value >> 16;
          uint8_t g = wsleds[i].value >> 8;
          uint8_t b = wsleds[i].value;
          r = (wsleds[i].r1 - wsleds[i].r2) * fastPulsePhase / 256 + wsleds[i].r2;
          g = (wsleds[i].g1 - wsleds[i].g2) * fastPulsePhase / 256 + wsleds[i].g2;
          b = (wsleds[i].b1 - wsleds[i].b2) * fastPulsePhase / 256 + wsleds[i].b2;
        wsleds[i].value = r << 16 | g << 8 | b;
        ws2812_set(wsleds[i].led, r, g, b);
      }
  }
  ws2812_refresh();
}

// Set module I2C address
void setAddr(uint8_t addr) {
  Wire.setSCL(SCL_PIN);
  Wire.setSDA(SDA_PIN);
  Wire.begin(addr, true);
  i2cAddr = addr;
  Wire.onRequest(onI2Crequest);
  Wire.onReceive(onI2Creceive);
}

// Reset and listen for new I2C address
void reset() {
  ws2812_set_all(44, 66, 100);
  for (uint16_t i = 0; i < WSLEDS; ++i)
    wsleds[i].mode = WS2812_MODE_ON;
  Serial.println("RESET");
  setAddr(LEARN_I2C_ADDR);
  configured = false;
  reset_time = millis() + 80;
}

// Initialise module
void setup(){
  Serial.begin(9600);
  SystemClock_Config();
  //Disable next module
  pinMode(NEXT_MODULE_PIN, OUTPUT);
  digitalWrite(NEXT_MODULE_PIN, LOW);

  ws2812_init(WSLEDS); // Initalise WS2812 (via SPI) before GPI to allow resuse of MOSI & SCLK pins
  for (uint16_t i = 0; i < WSLEDS; ++ i) {
    wsleds[i].led = i;
  }

  uint8_t switch_gpis[] = GPI_PINS;
  for (uint16_t i = 0; i < SWITCHES; ++i) {
    switches[i].gpi = switch_gpis[i];
    pinMode(switch_gpis[i], INPUT_PULLUP);
  }
  uint8_t adc_gpis[] = ADC_PINS;
  for (uint16_t i = 0; i < ADCS; ++i) {
    adcs[i].gpi = adc_gpis[i];
  }
  reset();
  pinMode(PC13, OUTPUT); // activity LED
  //delay(2000);
  //Serial.printf("Module 0x%04X initalised\n", MODULE_TYPE);
}

// Main process loop
void loop() {
  static bool led_on = false;
  static int uptime = 0;
  static int next_second = 0;
  static int loop_count = 0;
  static bool next_reset = false;

  static int selected_led = 0;
  static uint8_t mode = 0;

  ++loop_count;
  uint32_t now = millis();

  if(now >= next_second) {
    next_second = now + 1000;
    ++uptime;
    //Serial.printf("Uptime: %d cycles/sec: %d\n", uptime, loop_count);
    if (configured)
      led_on = (uptime % 4) == 0;
    else
      led_on = !led_on;
    digitalWrite(PC13, !led_on);
    loop_count = 0;
  }
  if (Serial.available()) {
    char c = Serial.read();
    if (c > '0' && c <= '9' && c - '0' < WSLEDS)
        selected_led = c - '1';
    else
      switch(c) {
        case '+':
          ++selected_led;
          break;
        case '-':
          --selected_led;
          break;
        case '!':
          reset();
          break;
        case '?': {
          int ms = now;
          int s = ms / 1000;
          ms %= 1000;
          int m = s / 60;
          s %= 60;
          int h = m / 60;
          m %= 60;
          int d = h / 24;
          h %= 24;
          Serial.printf("riban modular\nI2C address: 0x%02X Type: 0x%04X Uptime: %d days %02d:%02d:%02d.%04d\n", i2cAddr, MODULE_TYPE, d, h, m, s, ms);
          break;
        }
        case 'o':
          wsleds[selected_led].mode = WS2812_MODE_ON;
          break;
        case 'O':
          wsleds[selected_led].mode = WS2812_MODE_OFF;
          break;
        case 'i':
          wsleds[selected_led].mode = WS2812_MODE_ON2;
          break;
        case 'f':
          wsleds[selected_led].mode = WS2812_MODE_SLOW_FLASH;
          break;
        case 'F':
          wsleds[selected_led].mode = WS2812_MODE_FAST_FLASH;
          break;
        case 'p':
          wsleds[selected_led].mode = WS2812_MODE_SLOW_PULSE;
          break;
        case 'P':
          wsleds[selected_led].mode = WS2812_MODE_FAST_PULSE;
          break;
      }
  }

  if (reset_time < now)
  {
    reset_time = -1;
    for (uint16_t i = 0; i < WSLEDS; ++i)
      wsleds[i].mode = WS2812_MODE_OFF;
  }
  processSwitches(now);
  processAdcs(now);
  processWs2812(now);
}

// Handle received I2C data
void onI2Creceive(int count) {
  //Serial.printf("onI2Creceive(%d)\n", count);
  if (count) {
    i2cCommand = Wire.read();
    --count;
    //Serial.printf("  Command: 0x%02X\n", i2cCommand);
  }
  switch(i2cCommand) {
    case 0xfd: // Test
      Serial.println("TEST");
      break;
    case 0xfe: // Set I2C address
      if (!configured && count) {
        uint8_t addr = Wire.read();
        --count;
        //Serial.printf("Set I2C address >> 0x%02X\n", addr);
        if (addr >= 10 && addr < 111) {
          setAddr(addr);
          configured = true;
          digitalWrite(NEXT_MODULE_PIN, HIGH);
          //Serial.printf("  Changed I2C address to %02x\n", i2cAddr);
        }
      }
      break;
    case 0xff: // Reset
      reset();
      break;
    case 0xF1: // Set WS2812 mode and primary colour
    case 0xF2: // Set WS2812 mode and secondary colour
      if (count) {
        uint8_t led = Wire.read();
        --count;
        if (led < WSLEDS) {
          if (count == 1 || count == 4) {
            wsleds[led].mode = Wire.read();
            --count;
          }
          if (count == 3) {
            if (i2cCommand == 0xF1) {
              wsleds[led].r1 = Wire.read();
              wsleds[led].g1 = Wire.read();
              wsleds[led].b1 = Wire.read();
            } else {
              wsleds[led].r2 = Wire.read();
              wsleds[led].g2 = Wire.read();
              wsleds[led].b2 = Wire.read();
            }
            count -= 3;
          }
          //Serial.printf("  LED %d mode %d colour (%d,%d,%d)\n", led, wsleds[led].mode, wsleds[led].r1, wsleds[led].g1, wsleds[led].b1);
        }
      }
      break;
    case 0xF3: // Turn off all LEDs temporarily
      if (count) {
        ledMute = Wire.read();
        --count;
        if(ledMute)
          ws2812_refresh(ledMute);
      }
      break;
  }
  while (count) {
    Wire.read();
    --count;
  }
}

// Handle I2C request for data - assume command was set before request
void onI2Crequest() {
  //Serial.printf("onI2Crequest cmd: 0x%02X\n", i2cCommand);
  static uint32_t response; // Response is always 3 bytes: 23:16=addr, 15:0=value
  static uint8_t readSessionPos = 0; // Index of session last read value
  static uint64_t readMask;
  response = i2cCommand << 16;
  //Serial.printf("onI2Crequest cmd: 0x%02X\n", i2cCommand);

  if (i2cCommand == 0) {
    // Get next changed value
    if (changedFlags) {
      for (; readSessionPos < 64; ++readSessionPos) {
        readMask = (1ULL << readSessionPos);
        if (readMask & changedFlags) {
          if (readSessionPos < 0x10)
            response = ((0x10 + readSessionPos) << 16) | switchValues[readSessionPos];
          else if (readSessionPos < 0x10 + ADCS) {
            if (adcs[readSessionPos - 0x10].value != adcs[readSessionPos - 0x10].lastValue) {
              response = ((0x10 + readSessionPos) << 16) | adcs[readSessionPos - 0x10].value;
              adcs[readSessionPos - 0x10].lastValue = adcs[readSessionPos - 0x10].value;
            }
          }
          changedFlags &= ~readMask; // clear flag
          ++readSessionPos;
          break;
        }
      }
      if (readSessionPos > 63)
        readSessionPos = 0;
    } else {
      readSessionPos = 0;
    }
  } else if (i2cCommand < 0x10) {
    // General commands
  } else if (i2cCommand < 0x20) {
    // Get first bank of 32 switches
    response |= switchValues[i2cCommand - 0x10];
    //Serial.printf("GPI bank %d=%d\n", i2cCommand - 0x10, response);
  } else if (i2cCommand - 0x20 < ADCS) {
    response |= adcs[i2cCommand - 0x20].value;
    //Serial.printf("ADC %d=%d\n", i2cCommand, response);
    //!@todo Handle multiplexed ADC
  } else if (i2cCommand == 0xF0) {
    response |= MODULE_TYPE;
    //Serial.printf("MODULE TYPE\n");
  } else {
    //Serial.printf("BAD %d\n", i2cCommand);
  }
  //Serial.printf("Responding with value 0x%02X,0x%02X,0x%02X\n", (response>>16)&0xFF, (response>>8)&0xFF, response&0xFF);
  Wire.write((uint8_t*)&response, 3);
  delayMicroseconds(10); // Need delay to avoid bad read but too long will corrupt WS2812 bus
}

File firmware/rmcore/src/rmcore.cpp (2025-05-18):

/*  riban modular
    Copyright 2023-2025 riban ltd <info@riban.co.uk>

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
    Core host application.
*/

#include "global.h"
#include "util.h"
#include "usart.h"
#include "moduleManager.h"
#include "version.h"

#include <getopt.h> // Provides getopt_long for command line parsing
#include <jack/jack.h> // Provides jack client
#include <map> // Provides std::map
#include <set> // Provides std::set
#include <stdlib.h> // Provides atoi
#include <csignal> // Provides signal
#include <fstream> // Provies ofstream for saving files
#include <iostream> // Provides stream operations like <<
#include <string> // Provides std::string
#include <iomanip> // Provides std::setw
#include <fcntl.h> // Provides file control constants
#include <readline/readline.h> // Provides readline CLI
#include <readline/history.h> // Provides history in readline CLI
#include <sys/select.h> // Provides select for non-blocking input
#include <algorithm> // Provides std::transform
#include <ctime> // Provides time & date
#include <nlohmann/json.hpp> // Provides json access
#include <filesystem> // Provides create_directory
#include <regex> // Provides regular expression manipulation

using json = nlohmann::json;

// Structure representing a detected panel
struct PANEL_T {
    uint8_t id; // CAN id of panel
    uint32_t type; // Panel type defined in config.json
    uint32_t uuid1; // Panel UUID [0..31]
    uint32_t uuid2; // Panel UUID [32..63]
    uint32_t uuid3; // Panel UUID [64..95]
    uint32_t version; // Panel firmware version
    uint32_t ts = 0; // Timestamp of last rx message (used to detect panel removal) seconds
    Module* module; // Pointer to module object
};

static const char* historyFile = ".rmcore_cli_history";
const char* swState[] = {"Release", "Press", "Bold", "Long", "", "Long"};
uint8_t g_poly = 0xff; // Current polyphony
jack_client_t* g_jackClient;
uint32_t g_xruns = 0;
std::string g_stateName;
std::time_t g_nextSaveTime = 0;
bool g_dirty = false;
std::string g_portName = "/dev/tty/S0"; // Serial port name
USART* g_usart = nullptr; // Pointer to serial port
json g_config; // Global configuration, stored as json structure
std::map <uint8_t, PANEL_T> g_panels; // Map of panel structures indexed by panel id
ModuleManager& g_moduleManager = ModuleManager::get();
std::time_t g_now = 0; // Current time stamp
std::time_t g_panelStart = 0; // Scheduled time to set modules to run mode
int g_exitCode = 0; // Program exit code. Set before calling handleSignal
bool g_run = true; // False to exit main loop

static const std::string CONFIG_PATH = std::getenv("HOME") + std::string("/modular/config");

/*  TODO
    Initialise display
    Initialise audio: check for audio interfaces (may be USB) and mute outputs 
    Initialise each panel: Get info, check firmware version, show status via panel LEDs
    Unmute outputs
    Show info on display, e.g. firmware updates available, current patch name, etc.
    In program loop:
        Adjust signal routing
*/

std::string toLower(std::string input) {
    std::transform(input.begin(), input.end(), input.begin(),
        [](unsigned char c) { return std::tolower(c); });
    return input;
}

void print_version() {
    info("%s %s (%s) Copyright riban ltd 2023-%s\n", PROJECT_NAME, PROJECT_VERSION, BUILD_DATE, BUILD_YEAR);
}

void print_help() {
    print_version();
    info("Usage: rmcore <options>\n");
    info("\t-p --poly\tSet the polyphony (1..%u)\n", MAX_POLY);
    info("\t-P --port\tSet the serial port (default: /dev/ttyS0)\n");
    info("\t-s --snapshot\tLoad a snapshot state from file\n");
    info("\t-v --version\tShow version\n");
    info("\t-V --verbose\tSet verbose level (0:silent, 1:error, 2:info, 3:debug\n");
    info("\t-h --help\tShow this help\n");
}

// Function to strip [x] suffix from poly jack names
std::string stripPolyName(const char* name) {
    std::string str(name);
    std::regex bracket_pattern(R"(\[\d+\]$)");
    return std::regex_replace(str, bracket_pattern, "");
}

// Function to connect jack ports
bool connect(std::string source, std::string destination) {
    std::string src = source + "(\\[[0-9]+\\])?$";
    std::string dst = destination + "(\\[[0-9]+\\])?$";
    const char **srcPorts = jack_get_ports(g_jackClient, src.c_str(), NULL, JackPortIsOutput);
    const char **dstPorts = jack_get_ports(g_jackClient, dst.c_str(), NULL, JackPortIsInput);
    if (!srcPorts) {
        error("Source port(s) not found when searching for %s\n", src.c_str());
        return false;
    }
    if (!dstPorts) {
        error("Destination port(s) not found when searching for %s\n", src.c_str());
        return false;
    }
    bool srcEnd = false, dstEnd = false, success = false;
    const char *srcPort, *dstPort;
    for (uint8_t poly = 0; poly < g_poly; ++poly) {
        //debug("Route poly idx %u/%u\n", poly, g_poly);
        if (srcEnd == false) {
            srcPort = srcPorts[poly];
            srcEnd = srcPorts[poly + 1] == NULL;
        }
        if (dstEnd == false) {
            dstPort = dstPorts[poly];
            dstEnd = dstPorts[poly + 1] == NULL;
        }
        success |= (0 == jack_connect(g_jackClient, srcPort, dstPort));
    }
    jack_free(srcPorts);
    jack_free(dstPorts);
    g_dirty |= success;
    return success;
}

// Function to disconnect jack ports
bool disconnect(std::string source, std::string destination) {
    std::string src = source + "(\\[[0-9]+\\])?$";
    std::string dst = destination + "(\\[[0-9]+\\])?$";
    const char **srcPorts = jack_get_ports(g_jackClient, src.c_str(), NULL, JackPortIsOutput);
    const char **dstPorts = jack_get_ports(g_jackClient, dst.c_str(), NULL, JackPortIsInput);
    if (!srcPorts) {
        error("Source port(s) not found when searching for %s\n", src.c_str());
        return false;
    }
    if (!dstPorts) {
        error("Destination port(s) not found when searching for %s\n", src.c_str());
        return false;
    }
    bool srcEnd = false, dstEnd = false, success = false;
    const char *srcPort, *dstPort;
    for (uint8_t poly = 0; poly < g_poly; ++poly) {
        if (srcEnd == false) {
            srcPort = srcPorts[poly];
            srcEnd = srcPorts[poly + 1] == NULL;
        }
        if (dstEnd == false) {
            dstPort = dstPorts[poly];
            dstEnd = dstPorts[poly + 1] == NULL;
        }
        success |= (0 == jack_disconnect(g_jackClient, srcPort, dstPort));
    }
    jack_free(srcPorts);
    jack_free(dstPorts);
    g_dirty |= success;
    return success;
}
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

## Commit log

2023-08-13 Implement I2C interface. Add module configuration. Add WS2812 LED control.
2023-08-13 Fixes I2C issues
2023-08-14 Add I2C command to turn LED on with colour 2
2023-08-14 Add ability to change LED colour and mode separately
2023-08-20 Add config for VCV modules. Reallocate GPI pins. Add function to temporarily turn all LEDs off. Synchronise pulse and flash across module (still need to sync between modules). Fast pulse LEDs on rese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
    [main.cpp]
2023-08-22 Add function to get changed value from module. Use 16-bit values instead of 32-bit. Include address of data in return message. Reduce I2C responses from 4 to 3 bytes. Add more info to serial debug in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
    [main.cpp]
2023-08-22 Fix setting i2c address
    [main.cpp]
2023-08-27 Use min/max for rack parameter scaling / offset. Implement routing logic including LED feedback. Reduce panel reset LED flash duration.
    [main.cpp]
2023-09-01 Do not use reset - use run GPI
    [panel_types.h]
2023-09-01 Add 10HP PCB
    [10hp.kicad_pcb, 10hp.sch]
2023-09-08 PCB for generic 10hp panel (r1) including front panel for bogaudio VCO
    [10hp.kicad_pcb, 10hp.sch, 10hp_generic.kicad_pcb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]
2023-09-08 Fixes PCB footprint for C27 & C29
    [10hp_generic.sch]
2023-09-08 Fixes some component values
    [10hp_generic.kicad_pcb, 10hp_generic.sch]
2023-09-09 R2 of generic PCB using different components
    [10hp_generic.kicad_pcb, 10hp_generic.sch]
2023-09-15 Add 1-wire module detection
2023-09-16 Adds brain front panel
    [front_10hp_bogaudio_vco.kicad_pcb]
2023-09-28 Fixes and ehancements
    [10hp_generic.sch]
2023-10-06 Refactor to use module id instead of I2C address - wip!
2023-10-09 More website stuff
    [10hp_generic.kicad_pcb]
2023-10-13 Improvements to generic 10HP board layout. Implement exponential moving average filter on ADC reads.
    [10hp_generic.kicad_pcb]
2023-10-13 Fixes VCO PWM/FM input swap. Fixes errors in refactor of multiple module hosting panels.
2023-11-11 Adds STM32F1 generic panel firmware using CAN bus - wip
2023-11-11 Fix panel type not being set
    [global.h]
2024-02-01 Implement WS2812 LED control
2024-02-01 Adjust LED flash/pulse rates
2024-02-01 Rationalise CAN messaging. Add switches.
2024-02-02 Use 10kbps CAN for testing - avoid unreliable CAN interferring with tests. Handle existing panels resetting / connecting to brain. (Reuse existing records.) Implement I2C to CAN message sending. Fix 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
    [global.h, main.cpp]
2024-02-06 Fixes CAN based detection
    [global.h, main.cpp, panel_types.h]
2024-02-06 Adds ADC and python test script
2024-02-06 Tuning EMA filter
2024-02-26 Rev 3 Firmware
    Replace I2C interface with CAN.
    Change from STM32F0 to STM32F1 processor.
    Panel detection now done on CAN so can remove 2 detect wires.
    [adcs.hpp, global.h, main.cpp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]
2024-02-26 Adds 10HP Generic PCB
    [10hp_generic.csv, 10hp_generic.kicad_sch]
2024-02-26 Adds front panels
    [bogaudio_lvcf.dxf, brain.dxf]
2024-02-29 PCB design for generic r3 (wip)
    [10hp_generic.kicad_pcb, 10hp_generic.kicad_sch]
2024-03-05 Rev 3 PCB routing done
    [10hp_generic.kicad_pcb, 10hp_generic.kicad_sch]
2024-03-07 Rev 3 boards complete - probably
    [10hp_generic.csv, 10hp_generic.kicad_pcb, 10hp_generic.kicad_sch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]
2024-03-08 R3 PCB and front panel
    [10hp_generic.kicad_pcb, 10hp_generic.kicad_sch, front_10hp_bogaudio_vco.kicad_pcb]
2024-04-05 Updated PCB fixing issues with r3: Reversed power pins on U1. Increase size of potentiometer anchors holes. Enable external high speed clock. Enable all LEDs, switches and pots.
    [10hp_generic.kicad_pcb, 10hp_generic.kicad_sch]
2024-04-08 Replace I2C with USART
    [global.h, main.cpp]
2024-04-09 Create brain STM32F103 firmware
2024-04-11 Fixes to generic 10hp schematic and PCB
    [10hp_generic.kicad_pcb, 10hp_generic.kicad_sch]
2025-04-24 Remove oscillator code from main. Use static header file for wavetable data. Add application to build wavetable data. Add square wave oscillator with PWM. Add code documentation. Fix copyright notice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
    [main.cpp, oscillator.cpp]
2025-04-25 Switch from alsa to jack. Implement plugin mechanism for modules.
2025-04-25 Improve and simplify configuration of plugins. Add one-pole filtering of oscillator frequency control to reduce zipping.
    [main.cpp, oscillator.cpp]
2025-04-26 Add MIDI. Add filter (not working properly yet). Use CV input to oscillator to set frequency based on 1v/oct. Fix segfault when setting param value.
    [main.cpp]
2025-04-28 Use jack samplerate. Implement envelope. Implement polyphony. Add oscillator waveform morph control.
    [main.cpp]
2025-04-28 Adds MIDI pitch bend. Adds MIDI CC. Save and restore routing.
2025-04-28 Add base MIDI CC parameter. Add VCO waveform morph CV input. Fix envelope decay parameter. Fix square wave pulse width. Add xrun monitor. Fix polyphony setting. Remove debug.
    [main.cpp, oscillator.cpp]
2025-04-28 Adds noise generator module
    [main.cpp]
2025-04-29 Add panel using UUID. Jack client name now includes UUID in hex. Remove noise from wavetable. Use 1Hz period for wavetable. Improve LPF code. Disconnect from jack on close.
    [global.h, main.cpp]
2025-04-29 Updated CMake to auto build wavetable. Change Node class to Module. Fix exception with jack callbacks when closing. Add extra filter types: LP, HP, BP, etc. Provide error, info, debug helper function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
    [global.h, main.cpp]
2025-05-01 Fixes switching polyphony
2025-05-06 Add LED check. Create config directories if missing. Fix addPanel.
    [main.cpp]
2025-05-07 Update CAN & USART comms protocol. Fix LED control. Implement better mapping of hardware panels to software modules.
    [global.h, main.cpp]
2025-05-07 Fixes snapshots not making all connections if run with different polyphony.
    [rmcore.cpp]
2025-05-09 Remove stale modules when panel messages timeout. Implement rmcore control of panels, e.g. setting run mode. Fix segfault in vco. Fix missing parameters in vco. Only register jack connect callback in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
    [global.h, main.cpp, rmcore.cpp]
2025-05-09 Remove .p (add panel) from CLI. (Panels need keep alive CAN messages). Fix typos. Resolve some todos.
    [rmcore.cpp]
2025-05-11 Change rmcore state to use arrays rather than objects. Fix debug output not being enabled early enough. Add try/catch around json access. Fix polyphony being set incorrectly by config. Handle jack se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
    [panel_types.h, rmcore.cpp]
2025-05-13 Fixes polyphonic mode by removing loading polyphony from snapshot. Module may have any quantity of MIDI inputs and outputs defined. Rationalise port names to use "output" or "input" and not "out" or 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
    [front_10hp_bogaudio_vco.kicad_pcb]
2025-05-15 Add individual CV range parameter for each MIDI CC (1V, 10V, +/-5V), Fix VCF output. Adds Bogaudio noise generator. Update docs.
2025-05-16 Fix VCF (using wrong in/outs). Optimise some plugins. (Do not check for connection on every frame.)
2025-05-18 Add delay and hold phases to envelope generator. Add linear, log & exponential curves to attack, decay and release phases. Add LED setMode function. Catch exceptions in CLI.
2025-05-19 Adds ladder filter. Some optimisation of Bogaudio VCO wrapper.
2025-05-19 Add CV inputs for cutoff and resonance to ladder filter.
2025-05-19 Adds VCF based on Moog ladder filter

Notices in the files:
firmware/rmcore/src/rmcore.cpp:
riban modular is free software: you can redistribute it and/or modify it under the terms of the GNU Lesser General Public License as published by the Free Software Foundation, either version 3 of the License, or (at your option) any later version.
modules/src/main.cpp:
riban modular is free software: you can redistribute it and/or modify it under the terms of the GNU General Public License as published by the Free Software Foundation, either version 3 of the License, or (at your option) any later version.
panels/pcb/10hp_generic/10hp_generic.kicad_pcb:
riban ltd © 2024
